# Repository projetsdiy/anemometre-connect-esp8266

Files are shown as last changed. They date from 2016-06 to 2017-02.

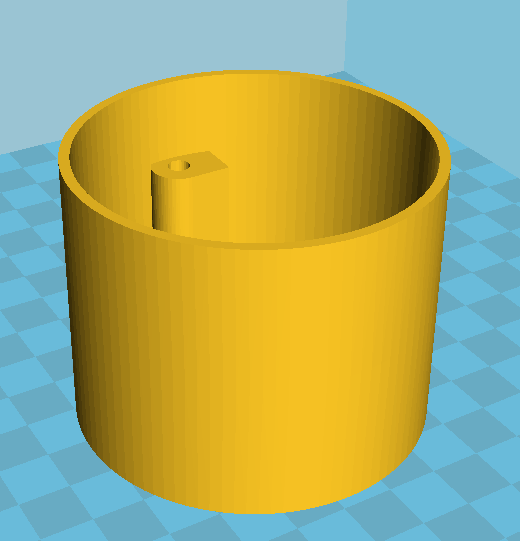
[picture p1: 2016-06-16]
Cura/Anémomètre - boitier.png

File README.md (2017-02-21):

# Anémomètre et girouette connectés à base d'ESP8266
Ce projet permet de réaliser un anémomètre et un girouette et de publier les mesures (par exemple sur un serveur domotique à l'aide du protocole MQTT). Tous les éléments seront à réaliser par impression 3D. Pour obtenir un objet connecté plus compact, le projet est basé sur une carte ESP8266 ESP-12F, <a href="http://www.banggood.com/D1-Mini-NodeMcu-Lua-WIFI-ESP8266-Development-Board-p-1044858.html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" target="_blank" rel="nofollow" data-mce-href="http://www.banggood.com/D1-Mini-NodeMcu-Lua-WIFI-ESP8266-Development-Board-p-1044858.html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">la Wemos D1 mini</a>.

Tutoriel pour la réalisation et toutes les explications : http://www.projetsdiy.fr/projet-diy-anemometre-girouette-objet-connecte-esp8266/

<h1>Contenu du projet Github </h1>
- Fichiers CAO aux formats STEP et f3d (Autodesk Fusion 360)
- Fichiers STL à imprimer en 3D
- Programme Arduino pour ESP8266

<h1>Articles pour les débutants</h1>
Si vous débutez avec l'ESP8266, voici plusieurs articles qui peuvent vous intéresser :
- <a href="http://www.projetsdiy.fr/esp8266-guide-de-choix-achat-projets-diy/" data-mce-href="http://www.projetsdiy.fr/esp8266-guide-de-choix-achat-projets-diy/">ESP8266 : guide de choix avant achat</a>
- <a href="http://www.projetsdiy.fr/esp8266-dht22-mqtt-projet-objet-connecte/">ESP8266 + DHT22 + MQTT : réaliser votre 1er objet connecté</a>
- <a href="http://www.projetsdiy.fr/esp-01-esp8266-flasher-firmware-origine/">ESP-01 : réinstaller le firmware d'origine (ESP8266)</a>
- <a href="http://www.projetsdiy.fr/personnaliser-firmware-nodemcu-esp8266-frightanic/">nodemcu-build: Firmware NodeMCU ESP8266 personnalisé (Frightanic)</a>

Egalement :
- <a href="http://www.projetsdiy.fr/jeedom-mqtt-objets-connectes-domotique-diy/" data-mce-href="http://www.projetsdiy.fr/jeedom-mqtt-objets-connectes-domotique-diy/">Jeedom + MQTT: associer un objet connecté DIY au Dashboard</a>

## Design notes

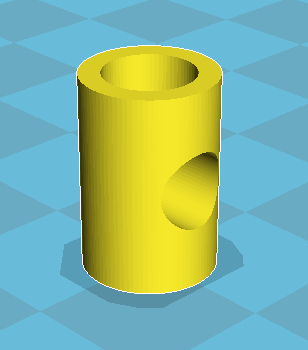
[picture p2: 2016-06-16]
Cura/Anémomètre - support aimants.png

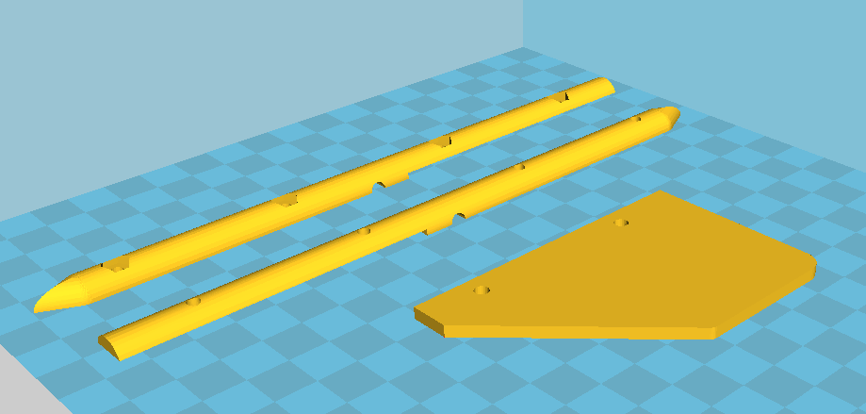
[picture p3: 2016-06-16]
Cura/Girouette .png

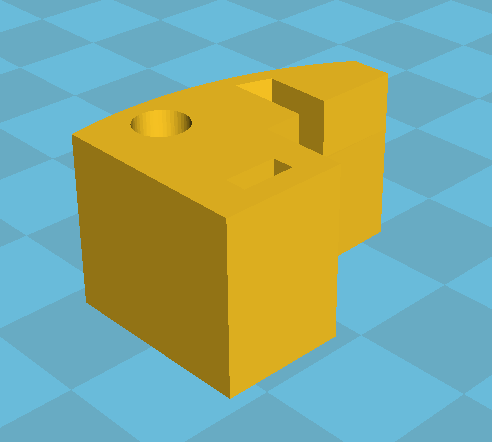
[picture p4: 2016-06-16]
Cura/Anémomètre - support us1881.png

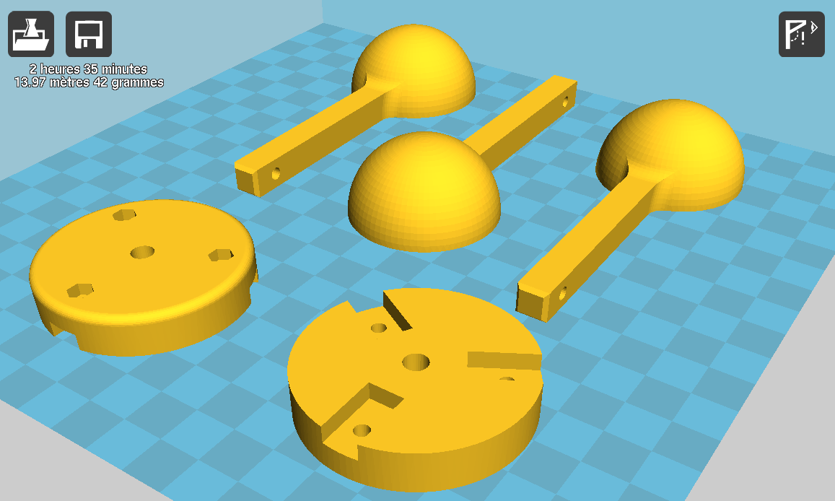
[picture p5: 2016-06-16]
Cura/Anémomètre - hélice.png

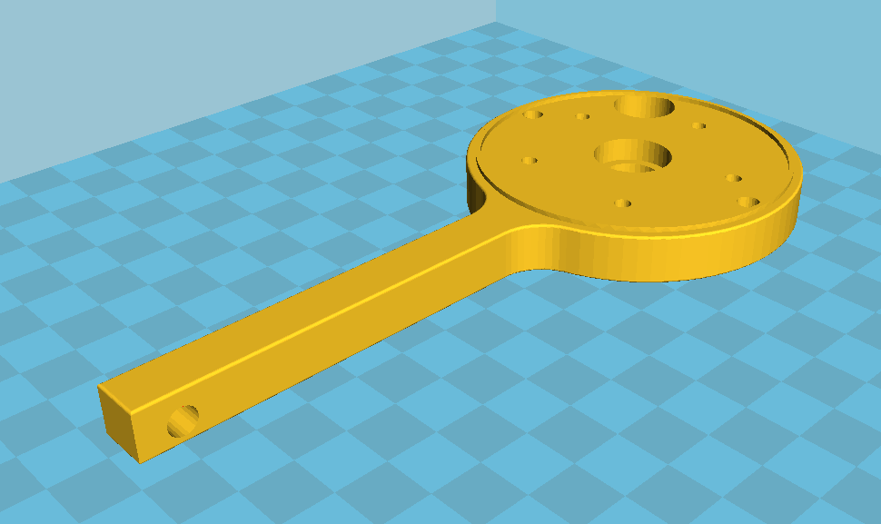
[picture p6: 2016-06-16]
Cura/Plaque de liaison.png

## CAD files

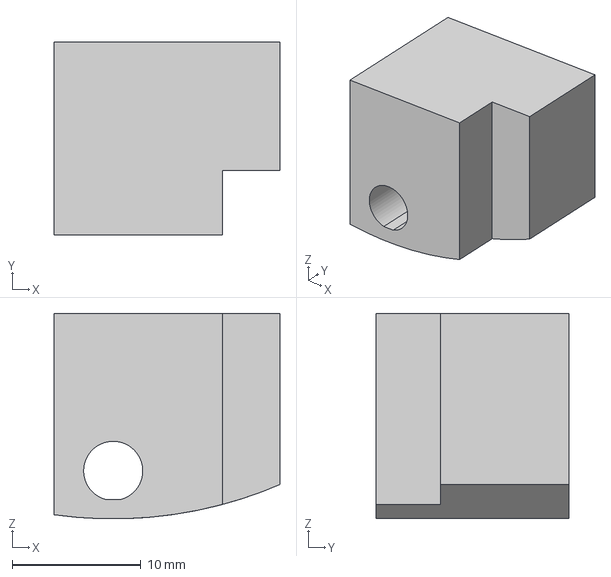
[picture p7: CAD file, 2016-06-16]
CAO/Anemometre.step
17.6 x 15.0 x 16.0 mm

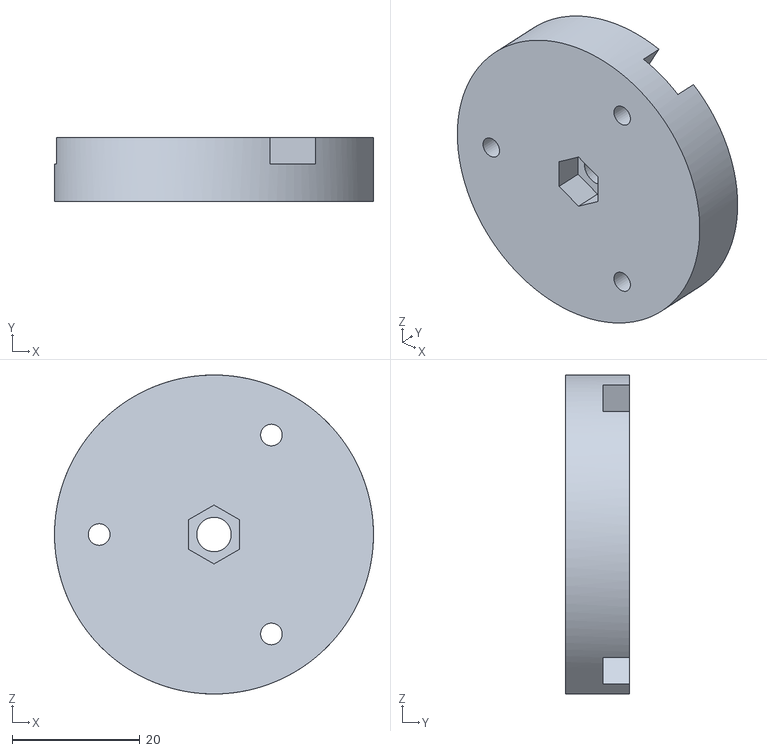
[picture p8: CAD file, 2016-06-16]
STL/anemometre - support helice inferieur.stl
50.0 x 10.0 x 50.0

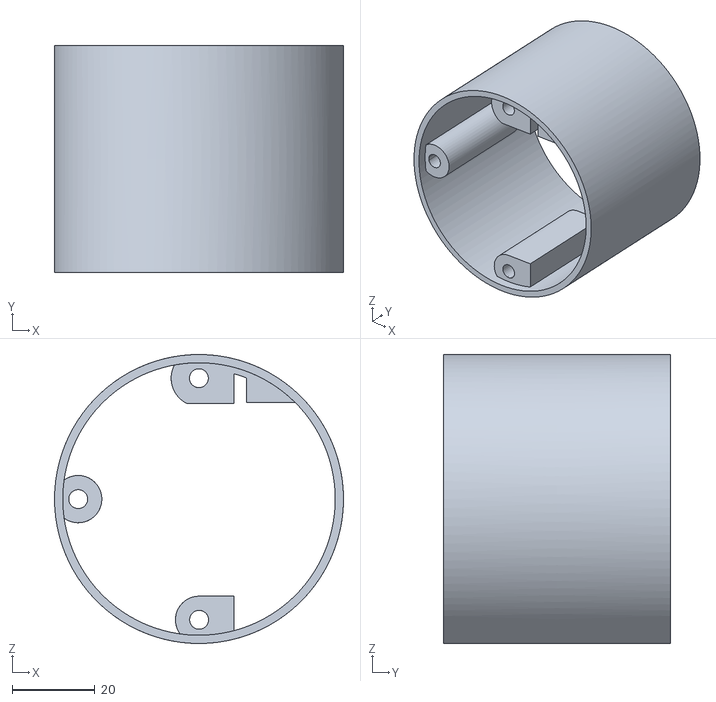
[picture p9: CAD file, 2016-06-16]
STL/Anemometre - corps.stl
70.0 x 55.0 x 70.0

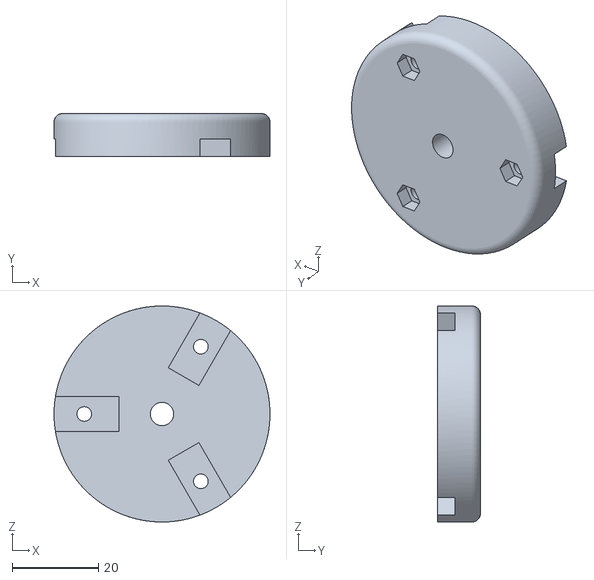
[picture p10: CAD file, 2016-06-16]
STL/anemometre - support helice superieur.stl
50.0 x 10.0 x 50.0

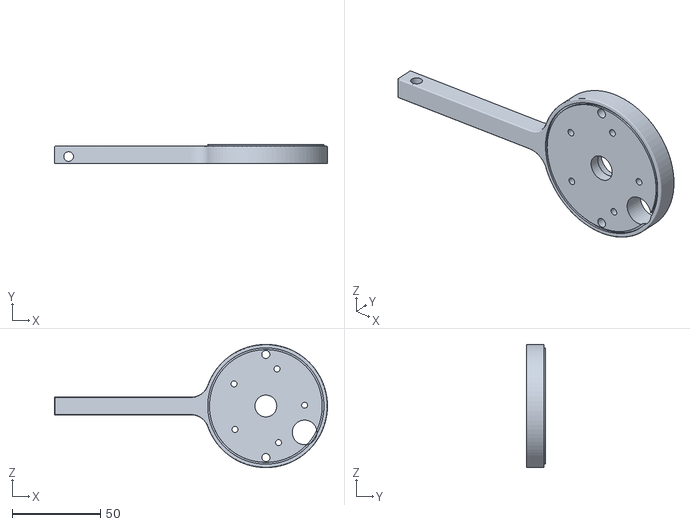
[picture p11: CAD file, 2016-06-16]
STL/Plaque de liaison.stl
155.0 x 11.0 x 70.0

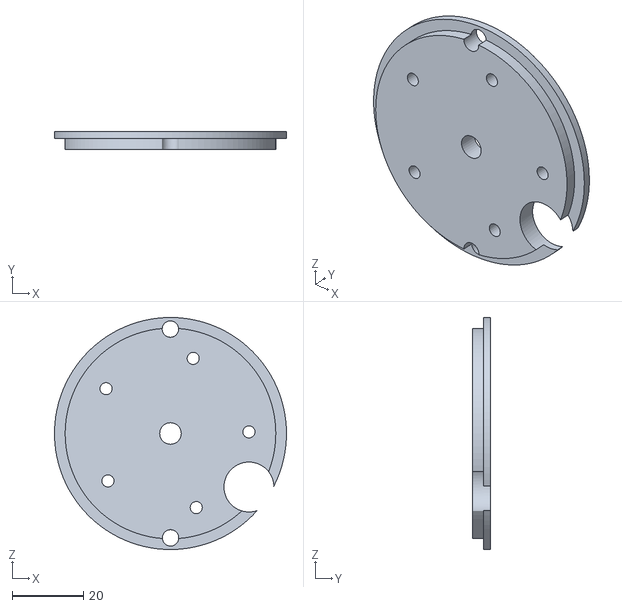
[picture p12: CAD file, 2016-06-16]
STL/Girouette - support Leds.stl
65.0 x 5.00 x 65.1

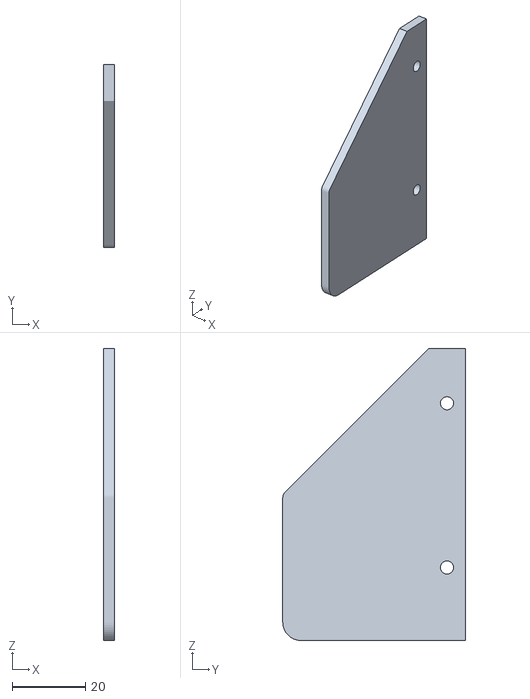
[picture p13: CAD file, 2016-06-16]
STL/Girouette - fleche.stl
3.00 x 50.0 x 80.0

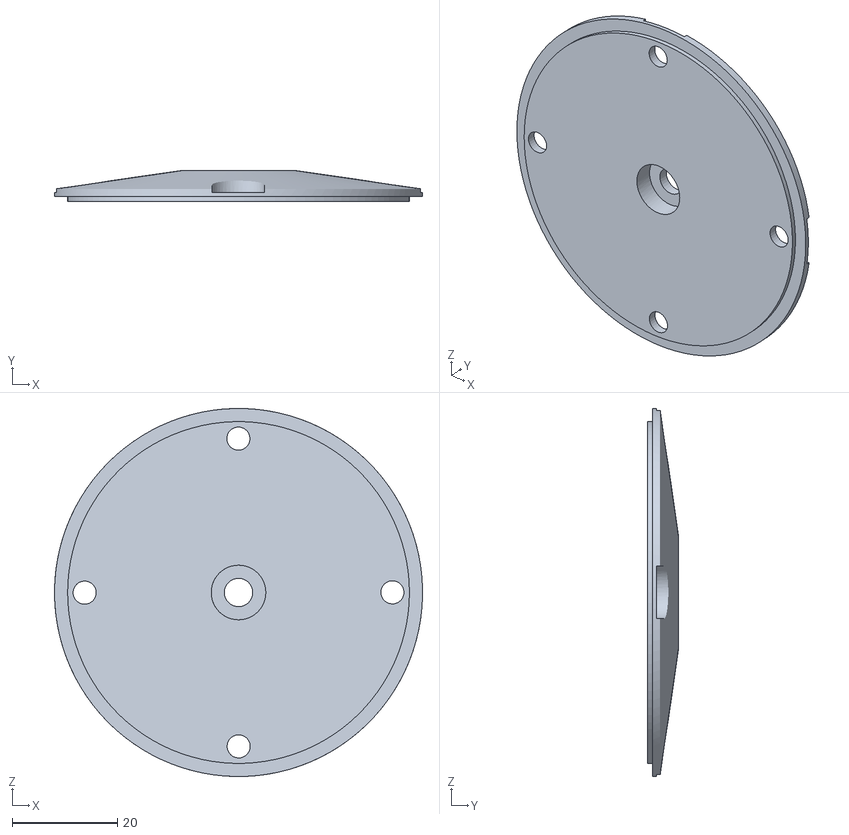
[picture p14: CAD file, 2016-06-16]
STL/Anemometre - couvercle.stl
70.0 x 5.93 x 70.0

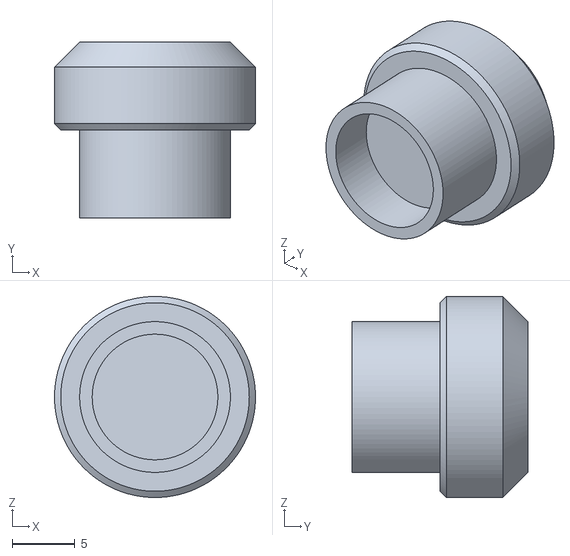
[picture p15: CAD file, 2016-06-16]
STL/anemometre - axe central.stl
16.0 x 14.0 x 16.0

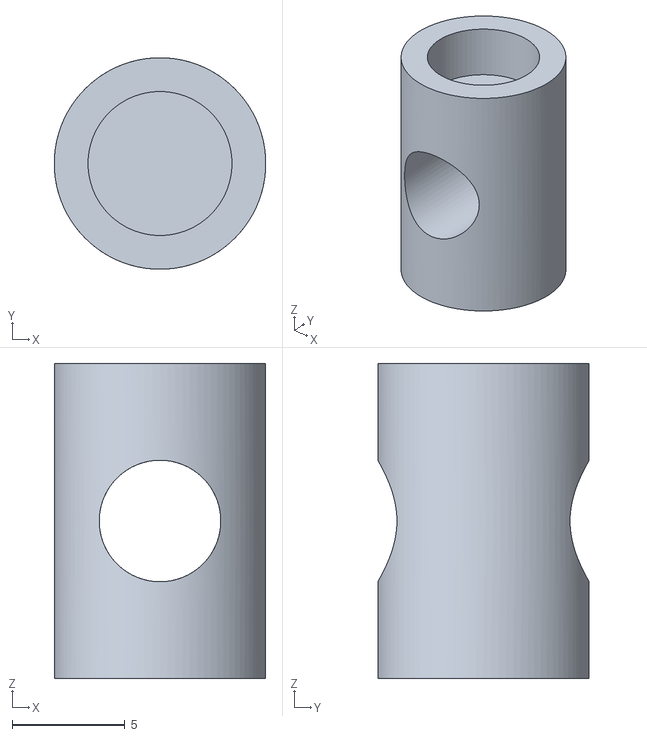
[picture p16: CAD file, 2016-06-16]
STL/Anemometre - support aimants.stl
9.40 x 9.40 x 14.0

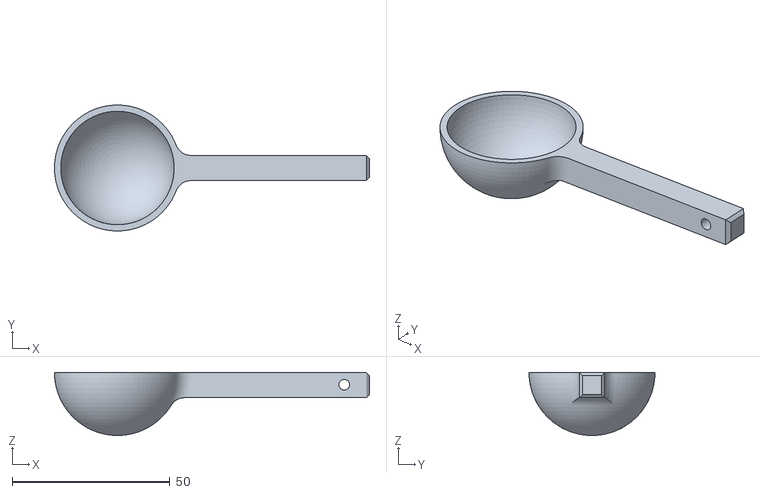
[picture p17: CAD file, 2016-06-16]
STL/anemometre - helice - x3.stl
100.0 x 40.0 x 20.0

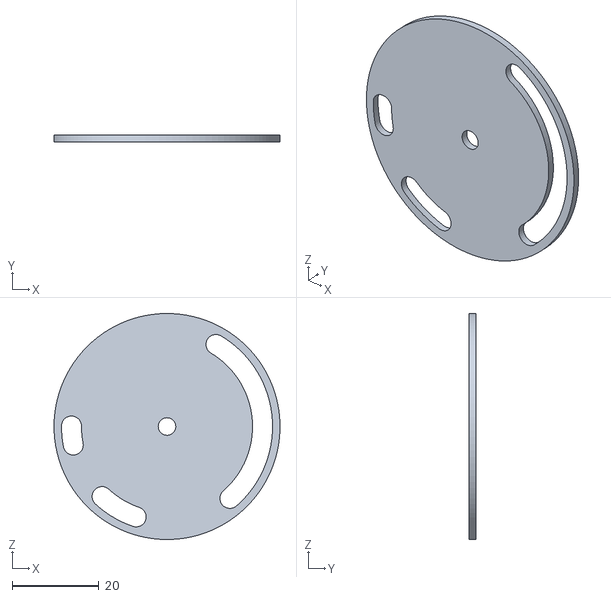
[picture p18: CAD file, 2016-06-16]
STL/Girouette - disque codeur.stl
52.0 x 1.50 x 52.0

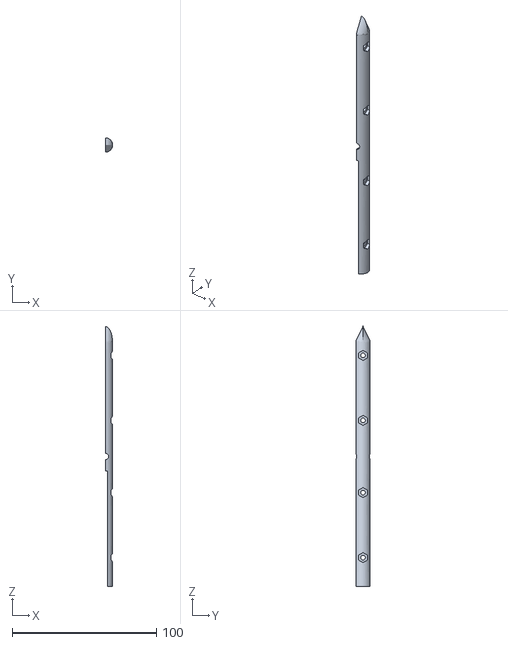
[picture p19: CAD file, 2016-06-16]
STL/Girouette - corps 2.stl
5.00 x 10.0 x 180.0

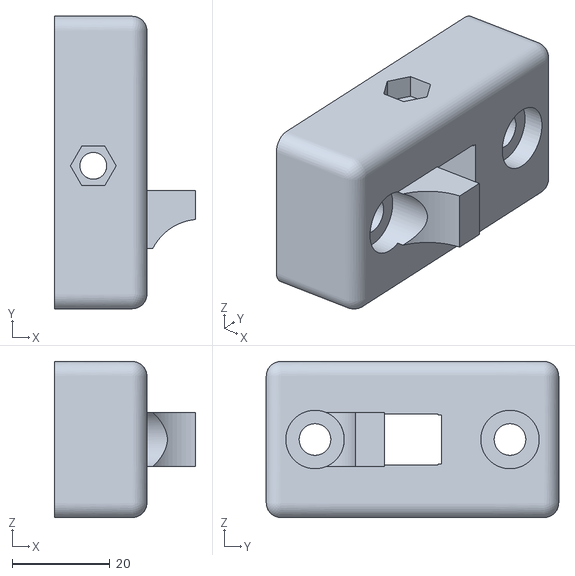
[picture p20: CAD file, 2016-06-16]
STL/Fixation - support mural.stl
29.0 x 60.0 x 32.0

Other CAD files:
STL/Anemometre - Blocage ESP.stl
STL/Anemometre - support us1881.stl
STL/Girouette - corps.stl
STL/Girouette - boitier.stl
CAO/Anemometre.f3d

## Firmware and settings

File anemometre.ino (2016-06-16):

/*
 * Anémomètre et girouette connecté à base d'ESP8266 (Wemos d1 mini)
 *  
 * Librairies nécessaires :
 *  - ESP8266Wifi : https://github.com/ekstrand/ESP8266wifi 
 *  - PubSubClient
 * 
 * http://www.projetsdiy.fr - Juin 2016 - Version 1.0
 * Licence : MIT
 * 
  */
#include <ESP8266WiFi.h>
#include <PubSubClient.h>
/*
 * Variables et paramètres de connexion WiFi
 * 
*/
#define wifi_ssid "SSID"
#define wifi_password "MOT_DE_PASSE"
#define mqtt_server "IP_MQTT"
#define mqtt_user "guest"     //s'il a été configuré sur Mosquitto
#define mqtt_password "guest" //idem

long lastMsg = 0;     //Horodatage du dernier message publié sur MQTT
long lastRecu = 0;

#define vitessems_topic "anemometre/vitesseVentMS"        // Topic Vitesse du vent (en m/s)
#define vitessekmh_topic "anemometre/vitesseVentKMH"      // Topic Vitesse du vent (en km/h)
#define direction_topic "anemometre/directionVent"    // Topic Direction du vent (lettre de la direction)

//Création des objets
   
WiFiClient espClient;
PubSubClient client(espClient);

volatile int rpmcount = 0;
volatile float vitVentMS = 0;
volatile float vitVentKMH = 0;
int rpm = 0;
unsigned long lastmillis = 0;
bool debug = false;

int pinBit0 = D7;
int pinBit1 = D6;
int pinBit2 = D5;
int pinBit3 = D4;
int pinBit4 = D3;
int pinHall = D2;

int bit0 = 0;
int bit1 = 0;
int bit2 = 0;
int bit3 = 0;
int bit4 = 0;

int dureeMesVitVent = 5000; // en ms, durée de mesure de la vitesse du vent. Choisir un multiple de 1000 pour le calcul de la vitesse du vent

//unsigned char girouette = 0;
byte girouette = 0;
String dirVent = "N";

void setup() {
  
  // put your setup code here, to run once:
  Serial.begin(9600);
  attachInterrupt(pinHall, rpm_vent, FALLING);
  pinMode(pinBit0, INPUT);
  pinMode(pinBit1, INPUT);
  pinMode(pinBit2, INPUT);
  pinMode(pinBit3, INPUT);
  pinMode(pinBit4, INPUT);
  //attachInterrupt(D7, bit0, FALLING);  

  setup_wifi();           //On se connecte au réseau wifi
  client.setServer(mqtt_server, 1883);    //Configuration de la connexion au serveur MQTT
  client.setCallback(callback);  //La fonction de callback qui est executée à chaque réception de message   
  
  Serial.print("GO");
}

//Connexion au réseau WiFi
void setup_wifi() {
  delay(10);
  Serial.println();
  Serial.print("Connexion a ");
  Serial.println(wifi_ssid);

  WiFi.begin(wifi_ssid, wifi_password);

  while (WiFi.status() != WL_CONNECTED) {
    delay(500);
    Serial.print(".");
  }

  Serial.println("");
  Serial.println("Connexion WiFi etablie ");
  Serial.print("=> Addresse IP : ");
  Serial.print(WiFi.localIP());
}

//Reconnexion
void reconnect() {
  //Boucle jusqu'à obtenur une reconnexion
  while (!client.connected()) {
    Serial.print("Connexion au serveur MQTT...");
    if (client.connect("ESP8266Client", mqtt_user, mqtt_password)) {
      Serial.println("OK");
    } else {
      Serial.print("KO, erreur : ");
      Serial.print(client.state());
      Serial.println(" On attend 5 secondes avant de recommencer");
      delay(5000);
    }
  }
}

void loop() {
  if (!client.connected()) {
    reconnect();
  }
  client.loop();
  
  getVitesseVent();
   
  getDirVent();
    
  client.publish(vitessems_topic, String(vitVentMS).c_str(), true);   // Publie la vitesse du vent en m/s
  client.publish(vitessekmh_topic, String(vitVentKMH).c_str(), true); // La vitesse du vent en km/h
  client.publish(direction_topic, String(dirVent).c_str(), true);     // La direction du vent
 
  //ESP.deepSleep(1000000 * 10, WAKE_NO_RFCAL); //Pour la prochaine version futur 
  //delay(500); //attente activation du deep sleep
  delay(2000);
}


void getVitesseVent() {
  if (millis() - lastmillis >= dureeMesVitVent ){ 
    detachInterrupt(pinHall); 

    rpm = rpmcount * ( 60 / ( dureeMesVitVent / 1000 ) ); 
    
    if ( rpm > 0 ) {
      vitVentKMH = ( rpm + 6.174 ) / 8.367;
      vitVentMS = ( ( ( rpm + 6.174 ) / 8.367 ) * 1000 ) / 3600; 
    } else {
      vitVentKMH = 0;
      vitVentMS = 0;
    }
    Serial.println(vitVentKMH);

    rpmcount = 0;           // Redémarre le compte tour
    lastmillis = millis();  // et réinitialise le chrono
    attachInterrupt(pinHall, rpm_vent, FALLING); // Rélance l'interruption du compte tour

  }


}

void getDirVent(){
  bit0 = not(digitalRead(pinBit0));
  bit1 = not(digitalRead(pinBit1));
  bit2 = not(digitalRead(pinBit2));
  bit3 = not(digitalRead(pinBit3));
  bit4 = not(digitalRead(pinBit4));
  
  girouette =  (bit4 * 16) + (bit3 * 8) + (bit2 * 4) + (bit1 * 2) + bit0;

  Serial.print(bit0); Serial.print(bit1); Serial.print(bit2); Serial.print(bit3); Serial.print(bit4);
  Serial.print(" => ");
  Serial.print(girouette);
  Serial.print(" Orientation");
  switch (girouette) {
    case 24: dirVent="N"; break;
    case 10: dirVent="NE"; break;
    case 18: dirVent="E"; break;
    //case 18: dirVent="SE"; break;
    case 16: dirVent="S"; break;
    case 2: dirVent="SW"; break;
    case 26: dirVent="O"; break;
    case 8: dirVent="NO"; break;
    default: dirVent="N"; break; 
  }
  Serial.println(dirVent);
}

void rpm_vent(){ 
  //Serial.println("Tour"),
  rpmcount++;
}


void callback(char* topic, byte* payload, unsigned int length) {

}
